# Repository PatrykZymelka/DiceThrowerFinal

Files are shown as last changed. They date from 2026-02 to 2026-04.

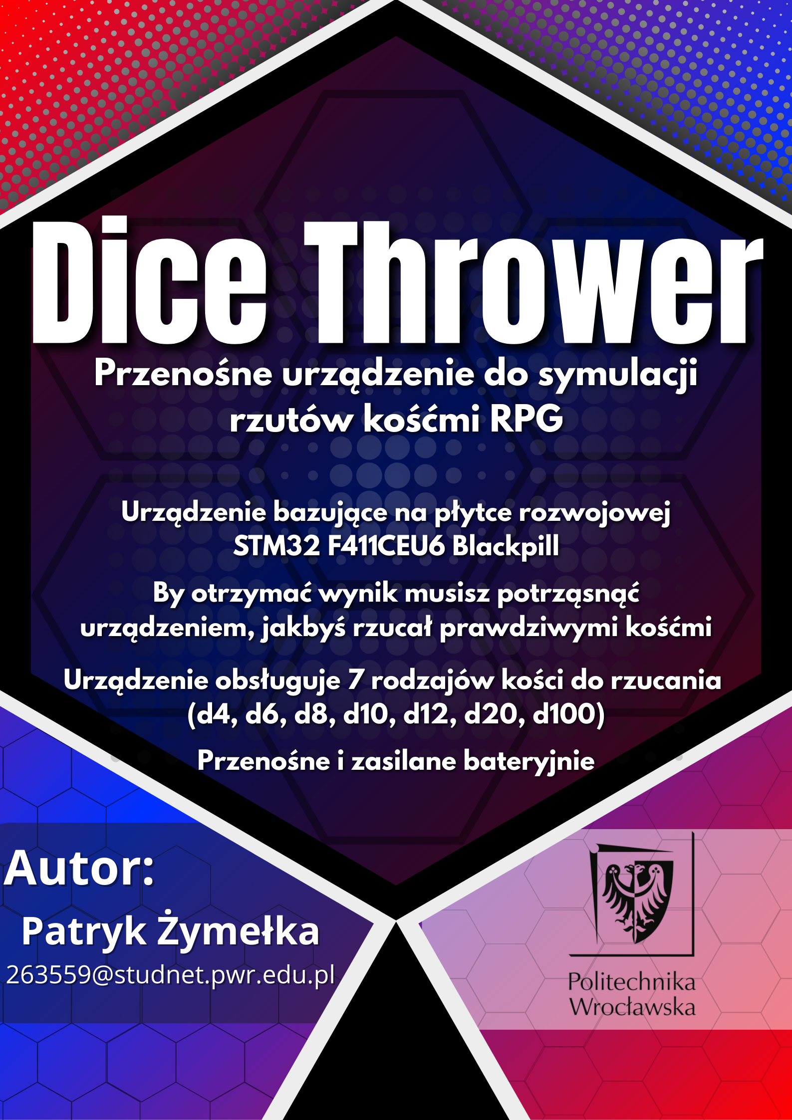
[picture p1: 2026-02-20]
Docs/Plakat.png

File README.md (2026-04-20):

Overview:

Dice thrower is a device that simulates the roll of multiple types and number of dice. With it is designed to help the user roll faster and get the result sooner, than with traditional physical dice. It is fully portable and runs on one rechargable LiON battery. located inside its case. To turn on this device you need to toggle the power switch on the right side of the device as seen below:



The device uses an OLED screen as its display, in the main menu you can see all the dice types that can be rolled and their amount, that was selected by the user.
We can roll the following 7 types of RPG dice:
- d4 (four sided die)
- d6 (six sided die)
- d8 (eight sided die)
- d10 (ten sided die)
- d12 (twelve sided die)
- d20 (twenty sided die)
- d100 (one hundred sided die)

Each type of die has its own assigned button located below the display. One additional button is the FUNC or function button which use will be explained in the results section.
To use the device firstly you need to choose the type and amount of dice you want to roll. To do so simply push the corresponding button to the type of die you want to roll. With each press you will increment the amount of dice rolled of the specific type.
You can see this on the below gif, in it we choose to roll four d20's and four d4's by simply holding down their buttons.



After selecting your dice to roll them you will need to gently shake the device, as if you were rolling real dice, when done correctly you will be notified by a quick tune comming from the speaker of the device. 
The gyroscope inside will detect sudden movement and sent the signal to the main board, to generate and display the results.
The results will be shown step by step, starting from the lowest type of die (in our case d4) and finishing on the largest type of die (in our example d20). On the result screen you will see each result individually on the top row, and the sum of all the rolls on the bottom row.
When you would want to see the next results or go back to the menu, simply bush the FUNC or function button located on the bottom right of the divice.
The following gif will display how this process works:



Hardware specification:
1) Microcontroller - Blackpill is based on the STM32F411CE microcontroller, which utilizes an ARM® 32-bit Cortex®-M4 core. This microcontroller operates at frequencies of up to 100 MHz, providing high performance for a wide range of applications. The board features 512 KB of Flash memory for firmware storage and 128 KB of SRAM for real-time data processing. The operating supply voltage ranges from 1.7V to 3.6V. Additionally, the board includes an RTC (Real-Time Clock), which is useful for applications requiring precise timekeeping. The STM32 Blackpill offers multiple communication interfaces, including USB 2.0, I2C, SPI/I2S, and USART, enabling easy integration with peripheral devices such as sensors, displays, audio devices, or communication modules. This development board can be programmed using popular development environments such as STM32CubeIDE or Arduino IDE, provided that STM32 core support and the required drivers are installed.
2) Battery - 18650 lithium-ion cell is a rechargeable battery with a typical capacity of 3000 mAh and a minimum capacity of 2900 mAh. Its nominal voltage is 3.7 V, although the actual voltage may vary depending on the state of charge. According to the specification, the maximum discharge current is 15 A, which is more than sufficient for this device.
3) Display - SH1106 1.3-inch 128x64 OLED display features a built-in SH1106 controller and supports multiple control platforms, including STM32 microcontrollers. It offers very low power consumption of 0.08 W, making it ideal for this project. The display operates in a voltage range from 3V to 5V and can function in temperatures from -30°C to 70°C. It communicates with the microcontroller via the SPI interface.
4) Accelotometer - LIS3DH 3-axis digital accelerometer, Adafruit 2809, enables acceleration measurements along the X, Y, and Z axes, allowing accurate detection of motion and device orientation. It operates at a supply voltage from 3V to 5V and communicates with the microcontroller using either I2C or SPI. The sensor provides 10-bit resolution and includes three additional analog inputs that can be read through I2C. Its measurement range is configurable and can be set to ±2 g, ±4 g, ±8 g, or ±16 g. It can also operate in Ultra Low Power Mode, where it consumes only 99 µA.
5) Step down voltage regulator -LM2596 step-down converter is a voltage reduction module operating with an input voltage range from 3.2 V to 35 V, with adjustable output voltage set via a potentiometer. Its output current ranges from 2 A to 3 A depending on thermal conditions and cooling, which is sufficient for this project. By placing the converter directly after the battery supply, stable voltage can be maintained throughout the entire operating time of the device.
6) Buzzer - MG15 buzzer is a small analog speaker with a power rating of 0.1 W and an impedance of 8 Ohms. It is used to generate an audible signal during the “dice roll” event. This is achieved by driving it with a PWM signal generated by the microcontroller.
7) Power switch - SS12T44 slide switch is a simple switch used in this project to turn the device power supply on and off.
8) Button switch - 6x6 mm THT tactile switches are standard momentary push-button switches and are fully sufficient for the requirements of this project.

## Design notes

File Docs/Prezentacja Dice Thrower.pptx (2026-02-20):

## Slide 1

- Dice Thrower
- Projekt urządzenia do symulacji rzutów kości RPG

Patryk Żymełka 263559

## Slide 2

- Koncepcja Projektu

Celem projektu jest stworzenie przenośnego urządzenia symulującego rzuty siedmioma standardowymi kośćmi wykorzystywanymi w grach fabularnych RPG (D4, D6, D8, D10, D12, D20, D100). Projekt umożliwi użytkownikowi wybór rodzaju i ilości kości a następnie potrząsając urządzeniem, wygeneruje losowy wynik, który zostanie wyświetlony na wbudowanym ekranie.

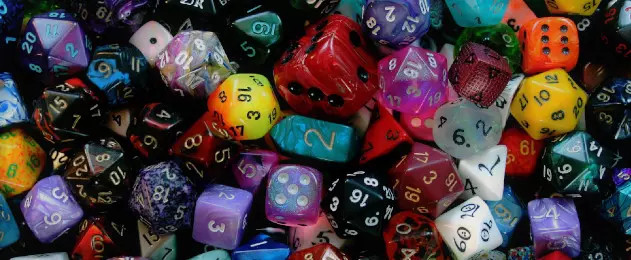
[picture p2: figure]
Zestawy kości Dungeons and Dragons – mechaniki i typowe zastosowania – Blog o RPG
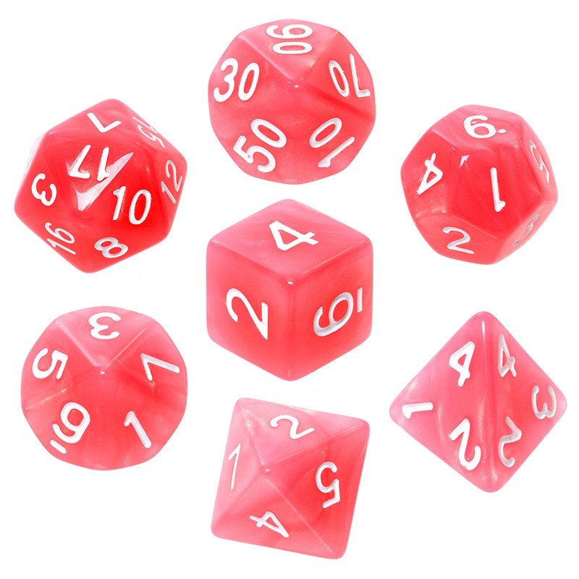
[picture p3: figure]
kości RPG Kamienie Księżycowe - Awenturyn - komplet 7 sztuk, zestaw kości - Xjoy.pl

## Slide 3

- Założenia Projektowe

- Symulator rzutów kości - Urządzenie musi mieć możliwość rzucania siedmioma rodzajami kości D4, D6, D8, D10, D12, D20, D100.
- Wyświetlanie wyników - By pokazać użytkownikowi wyniki urządzenie musi obsługiwać wyświetlacz OLED.
- Elementy Interaktywne:
A)Guziki do wybierania rodzaju i ilości kości
B)Wyświetlanie wyników poprzez potrząsanie urządzeniem
C)Element dźwiękowy przy potrząsaniu
- Przenośność - urządzenie musi być kompaktowe by można je było przenieść i używać poza domem.

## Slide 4

- ESP32 STM32F411CEU6 Blackpill Board
- Ogniwo 18650 3000mAh Li-On
- Wyświetlacz OLED SH1106 1,3" 128x64px
- 3-osiowy akcelerometr cyfrowy LIS3DH - Adafruit 2809
- Przetwornica step-down – LM2596
- Głośnik MG15 0,1W

- Główne elementy urządzenia

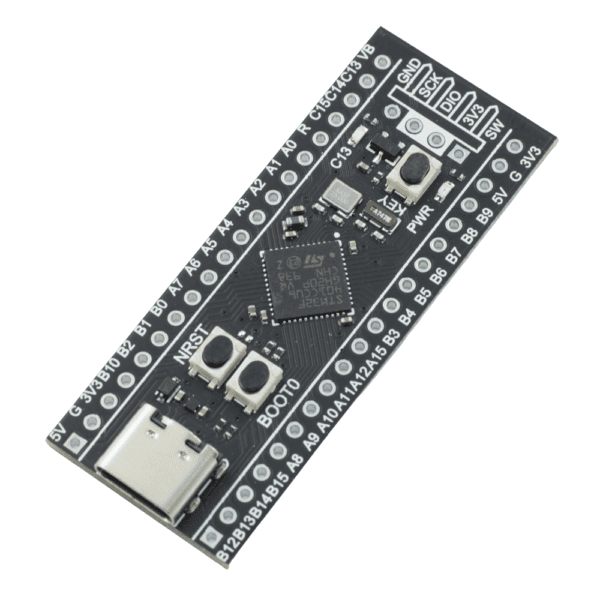
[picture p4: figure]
sklep_msalamon_STM32F4X1CXU6_EVAL_3
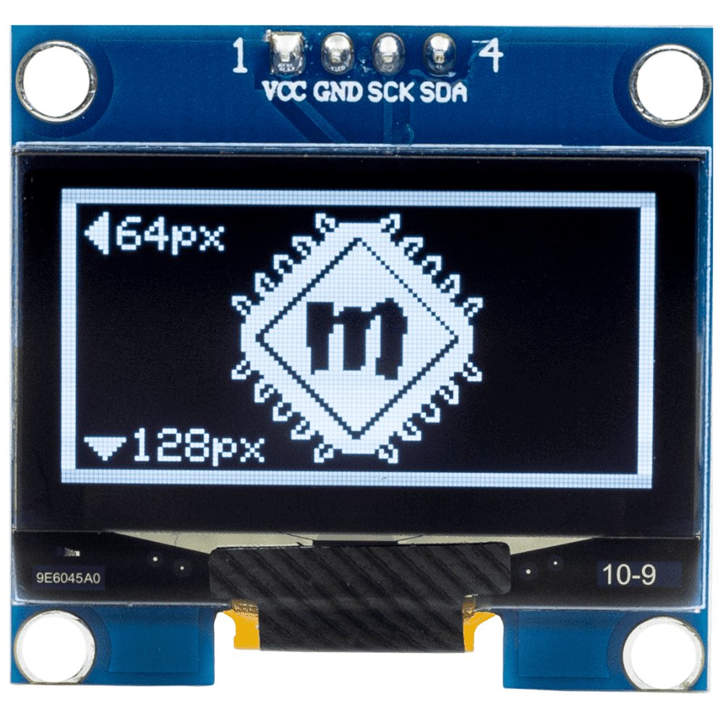
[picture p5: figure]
Wyświetlacz OLED 1,3" 128x64px I2C biały - Sklep msalamon
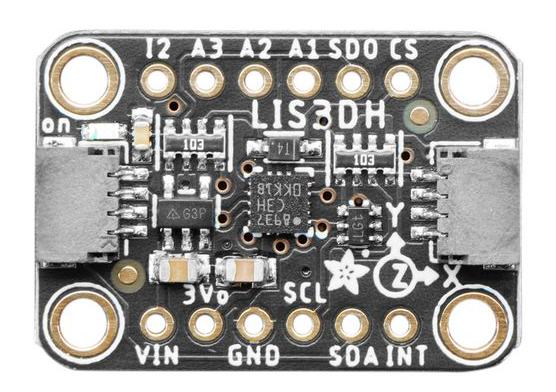
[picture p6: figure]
2809 | Adafruit Akcelerometr trzyosiowy LIS3DH, 5V | Distrelec Polska

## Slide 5

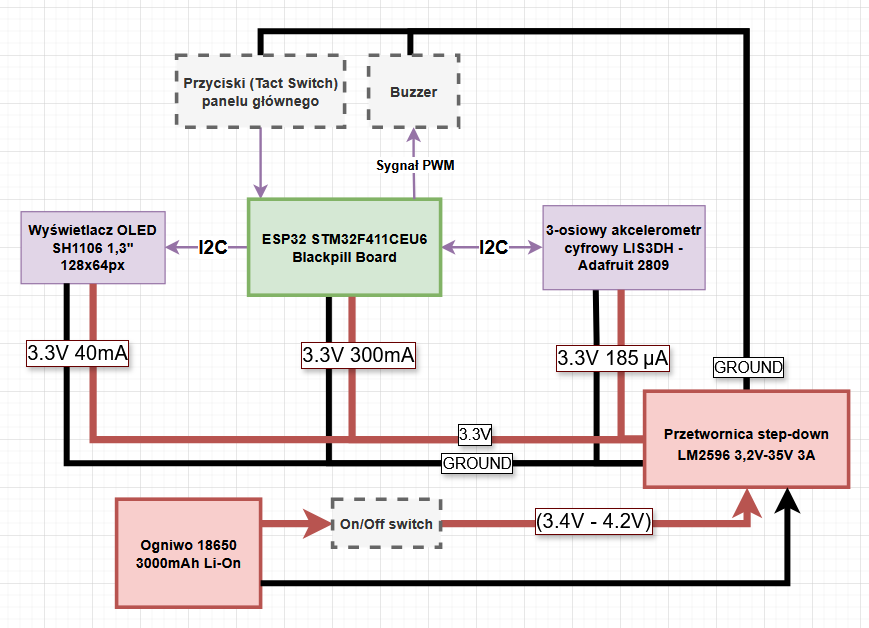
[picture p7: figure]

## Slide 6

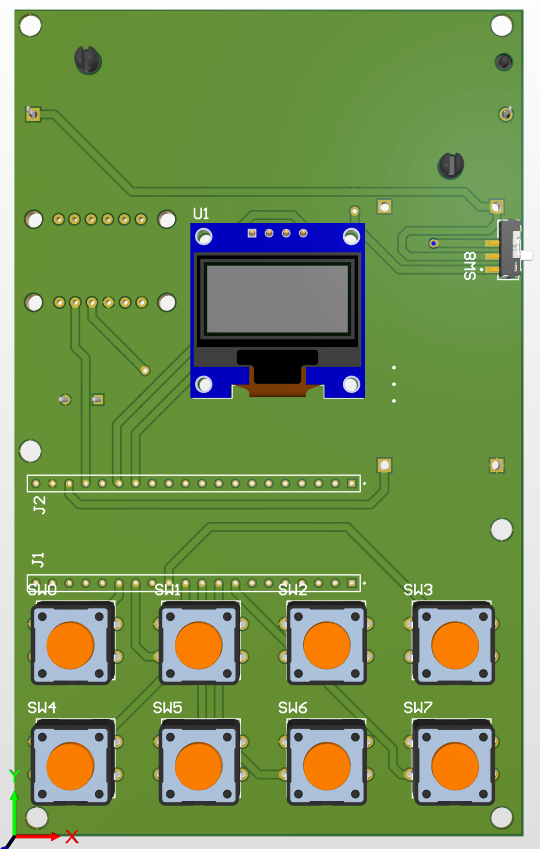
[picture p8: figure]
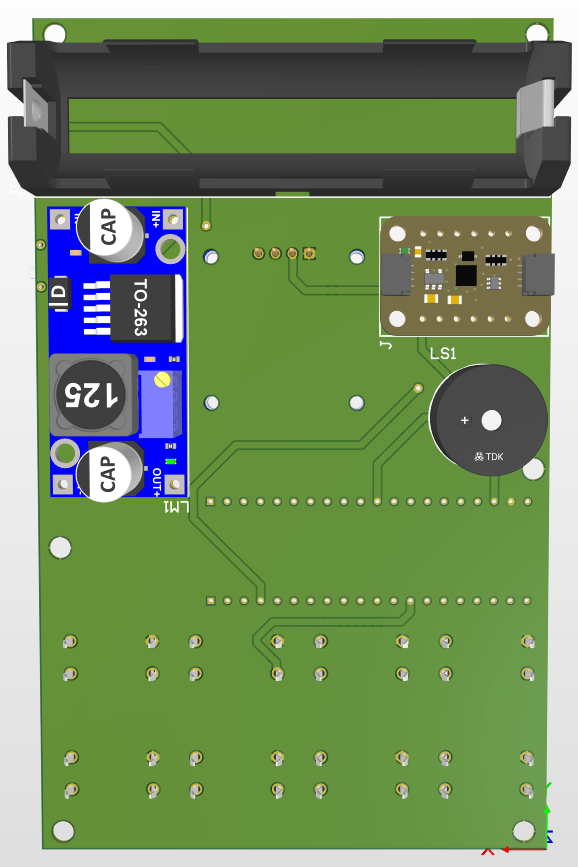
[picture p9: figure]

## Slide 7

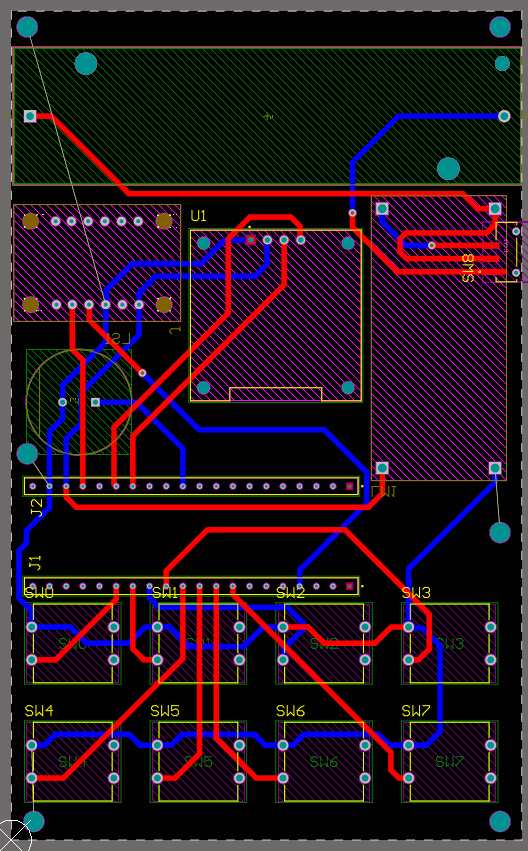
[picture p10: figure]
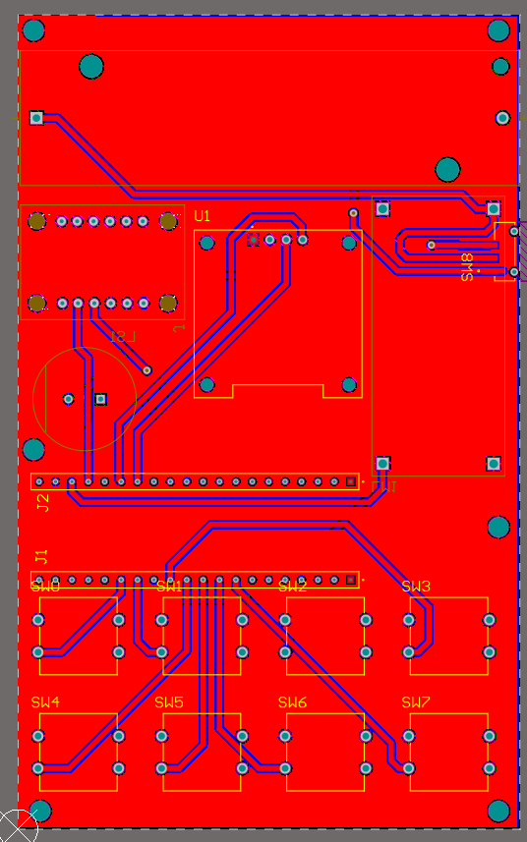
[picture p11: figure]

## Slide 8

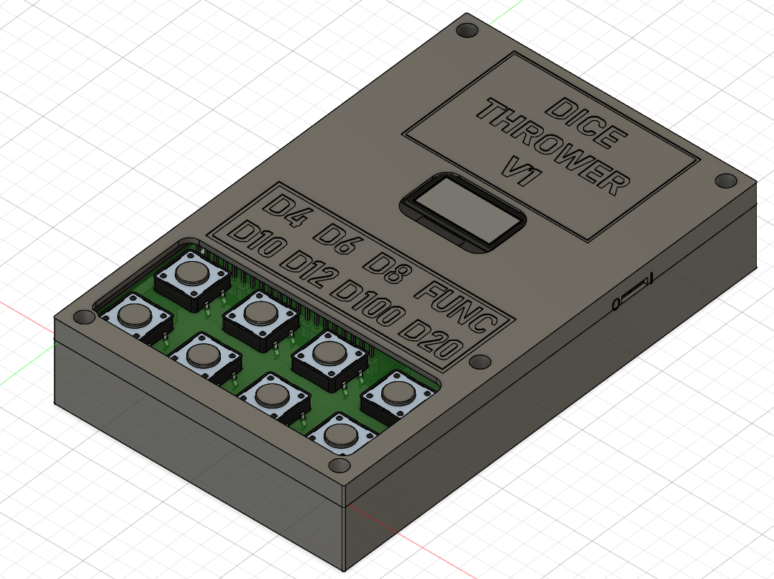
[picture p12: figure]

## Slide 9

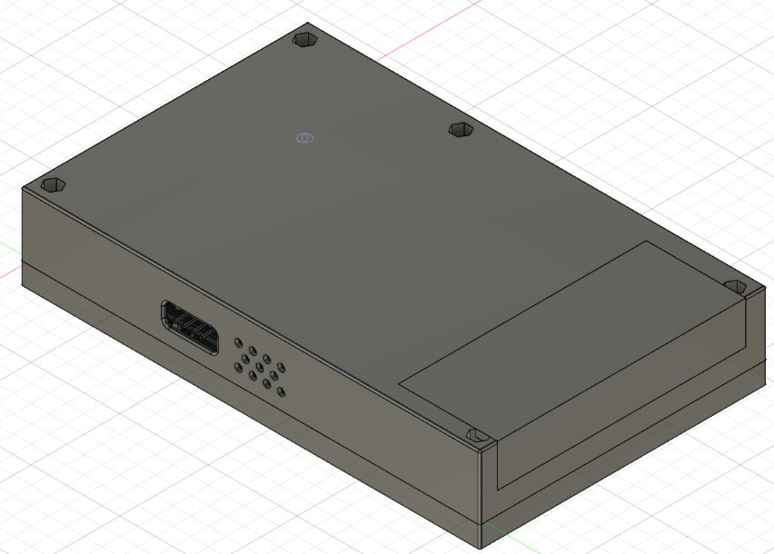
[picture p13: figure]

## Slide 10

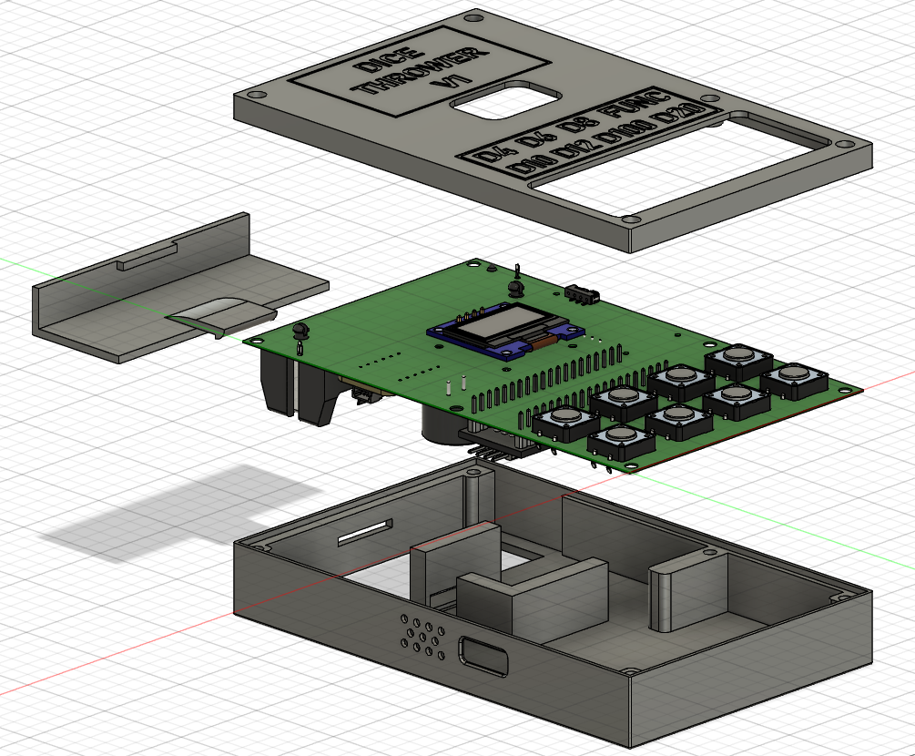
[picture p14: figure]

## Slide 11

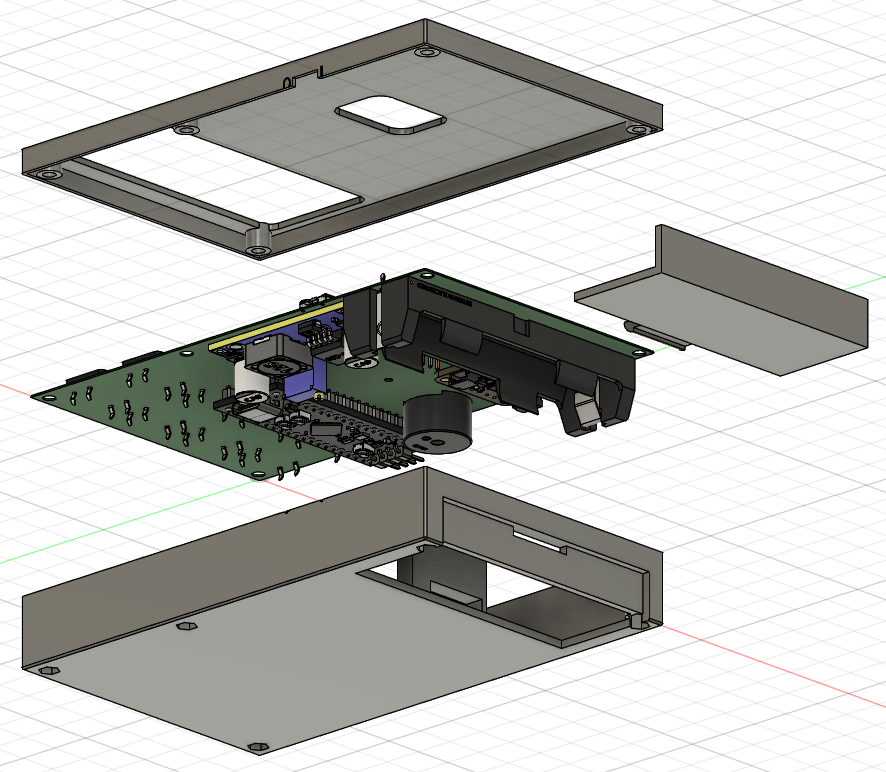
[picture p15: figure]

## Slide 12

- Diagram Logiki

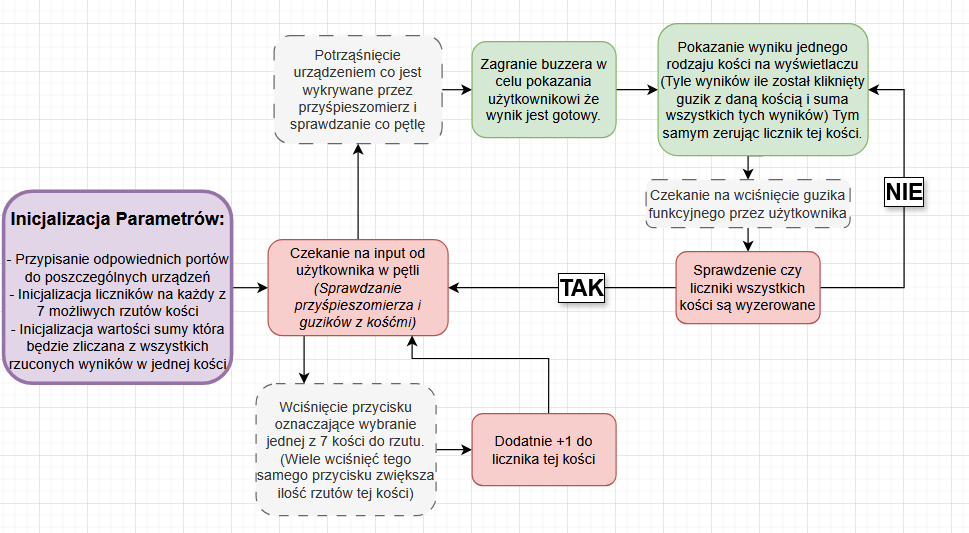
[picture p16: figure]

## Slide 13

- Zestawienie Kosztów

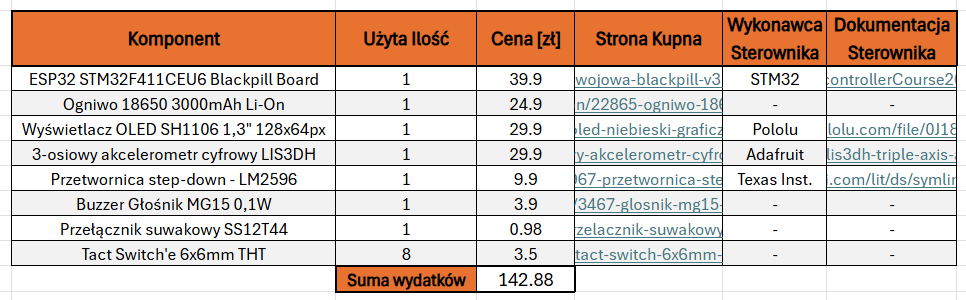
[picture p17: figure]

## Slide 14

- Dziękuję za uwagę

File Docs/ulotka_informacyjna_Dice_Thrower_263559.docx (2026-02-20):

Dice Thrower

Patryk Żymełka, Elektryczne systemy mechatroniki, II stopień, I semestr. W12N

Założenia projektowe: Celem projektu jest stworzenie przenośnego urządzenia symulującego rzuty siedmioma standardowymi kośćmi wykorzystywanymi w grach fabularnych RPG (D4, D6, D8, D10, D12, D20, D100). Projekt umożliwi użytkownikowi wybór rodzaju i ilości kości a następnie potrząsając urządzeniem, wygeneruje losowy wynik, który zostanie wyświetlony na wbudowanym ekranie. Dodatkowym elementem urządzenia będzie efekt dźwiękowy wydawany przy akcie potrząśnięcia urządzeniem.


Schemat blokowy | Parametry techniczne urządzenia: 1. ESP32 STM32F411CEU6 Blackpill - Płytka rozwojowa STM32 Blackpill oparta jest na mikrokontrolerze STM32F411CE, który wykorzystuje rdzeń ARM® 32-bit Cortex®-M4. 2. Wyświetlacz OLED SH1106 1,3" 128x64px - Wyświetlacz ten posiada wbudowany sterownik SSH1106. 3. 3-osiowy akcelerometr cyfrowy LIS3DH - Adafruit 2809 – Akcelerometr ten umożliwia pomiar przyspieszenia w trzech osiach w wybieralnym zakresie pomiarowym ±2 g, ±4 g, ±8 g lub ±16g. 4. Przetwornica step-down - LM2596 - Działa w zakresie od 3,2 V do 35 V napięcia wyjściowego oraz prądu wyjściowego do 3A.

Opis działania urządzenia: Użytkownik wybiera ilość i rodzaj kości które chce rzucić, wykonuje to poprzez klikanie odpowiednich guzików na urządzeniu. Po wybraniu tych parametrów powinien on potrząsnąć urządzeniem, co zostanie zarejestrowane przez przyśpieszomierz. W skutku czego urządzenie wyświetli wyniki poszczególnych rzutów na wyświetlaczu wraz z zagraniem muzyki z głośnika urządzenia.

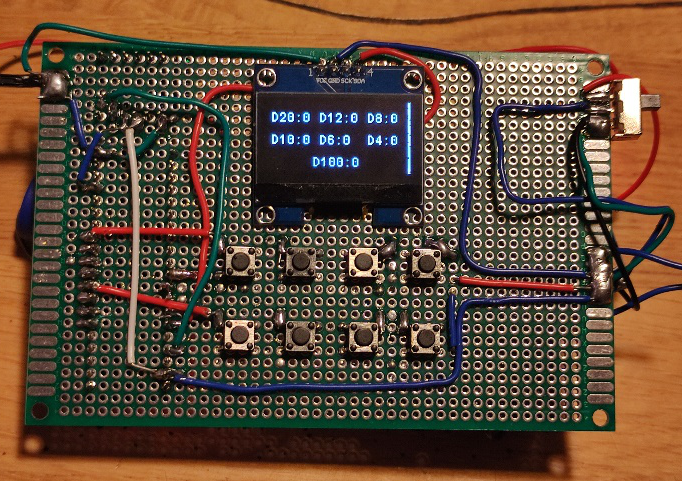
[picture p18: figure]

Wizualizacja Przyszłej wersji urządzenia | Zdjęcie gotowego urządzenia

Ewentualne dodatkowe informacje/ efekty pracy: Udało się stworzyć w pełni funkcjonalne fizyczne urządzenie widoczne na powyższym prawym zdjęciu.

Projekt zrealizowano w ramach kursu Systemy elektroniczne w mechatronice

Realizacja niniejszego projektu sfinansowana została ze środków W12/ K72/ autorów

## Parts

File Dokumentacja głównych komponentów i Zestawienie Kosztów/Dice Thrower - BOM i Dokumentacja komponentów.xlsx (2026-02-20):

Komponent | Użyta Ilość | Cena [zł] | Strona Kupna | Wykonawca Sterownika | Dokumentacja Sterownika
ESP32 STM32F411CEU6 Blackpill Board | 1 | 39.9 | https://botland.com.pl/stm32-discovery/19769-stm32f411ceu6-plytka-rozwojowa-blackpill-v31-z-mikrokontrolerem-stm32f411ceu6-weact-studio-5904422347536.html | STM32 | https://docs.scintilla.utwente.nl/cursus/MicrocontrollerCourse2015/STM32F411%20Reference%20Manual.pdf
Ogniwo 18650 3000mAh Li-On | 1 | 24.9 | https://botland.com.pl/akumulatory-li-ion/22865-ogniwo-18650-inr18650-f1hr-5c66c-3000mah.html | - | -
Wyświetlacz OLED SH1106 1,3" 128x64px | 1 | 29.9 | https://botland.com.pl/wyswietlacze-oled/8246-wyswietlacz-oled-niebieski-graficzny-13-128x64px-i2c-v2-niebieskie-znaki-5904422311339.html | Pololu | https://www.pololu.com/file/0J1813/SH1106.pdf
3-osiowy akcelerometr cyfrowy LIS3DH | 1 | 29.9 | https://botland.com.pl/akcelerometry/5295-lis3dh-3-osiowy-akcelerometr-cyfrowy-i2cspi-stemma-qt-adafruit-2809-5904422354312.html | Adafruit | https://learn.adafruit.com/adafruit-lis3dh-triple-axis-accelerometer-breakout/downloads
Przetwornica step-down - LM2596 | 1 | 9.9 | https://botland.com.pl/przetwornice-step-down/2967-przetwornica-step-down-lm2596-32v-35v-3a-5903351241397.html | Texas Inst. | https://www.ti.com/lit/ds/symlink/lm2596.pdf
Buzzer Głośnik MG15 0,1W | 1 | 3.9 | https://botland.com.pl/glosniki-analogowe/3467-glosnik-mg15-01w-8ohm-15x4mm-5903351245845.html | - | -
Przełącznik suwakowy SS12T44 | 1 | 0.98 | https://botland.com.pl/przelaczniki-spdt/8051-przelacznik-suwakowy-ss12t44-2-pozycyjny-5szt-5904422304218.html | - | -
Tact Switch'e 6x6mm THT | 8 | 3.5 | https://botland.com.pl/tact-switch/3495-tact-switch-6x6mm-5mm-tht-2pin-5szt-5904422307639.html | - | -
 | Suma wydatków | 142.88

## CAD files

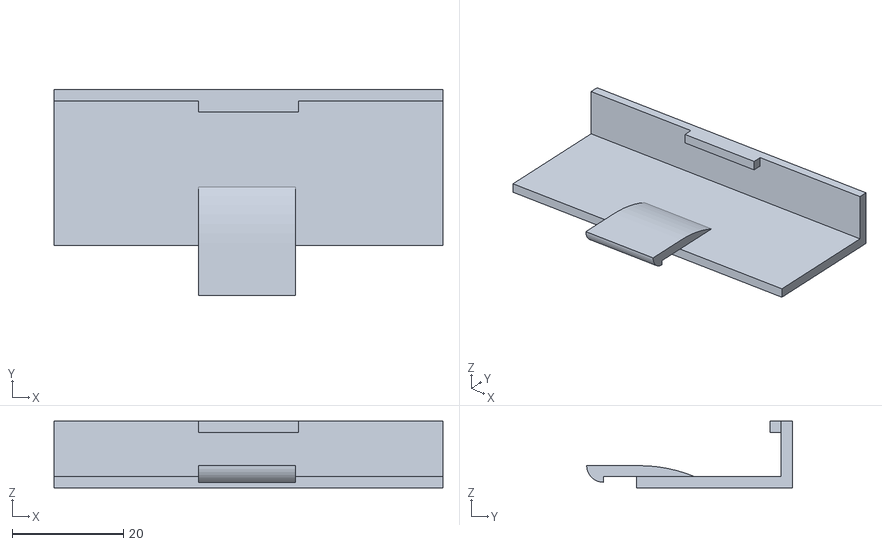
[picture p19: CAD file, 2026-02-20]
Dice Thrower Case - Fusion 360 files/Dice Thrower v13 - Battery Cover.stl
70.0 x 37.0 x 12.0

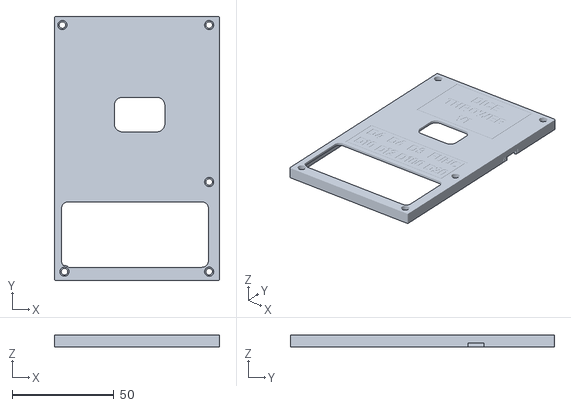
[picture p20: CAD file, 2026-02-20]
Dice Thrower Case - Fusion 360 files/Dice Thrower v13 - Top Part.stl
81.0 x 129.5 x 6.00

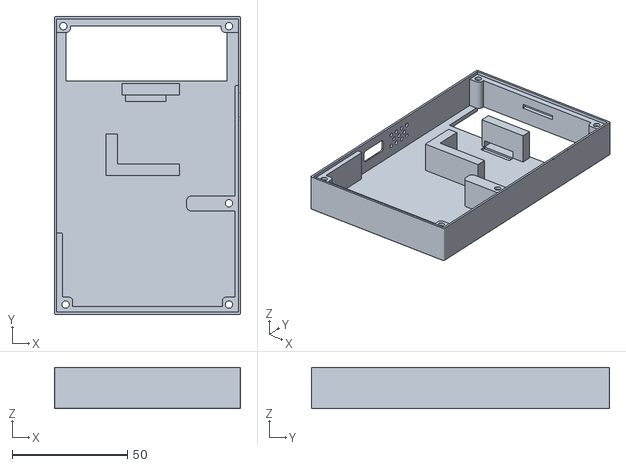
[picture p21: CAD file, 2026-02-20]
Dice Thrower Case - Fusion 360 files/Dice Thrower v13 - Bottom Part.stl
81.0 x 129.5 x 18.0

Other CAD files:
Dice Thrower Case - Fusion 360 files/Dice Thrower v12.f3d

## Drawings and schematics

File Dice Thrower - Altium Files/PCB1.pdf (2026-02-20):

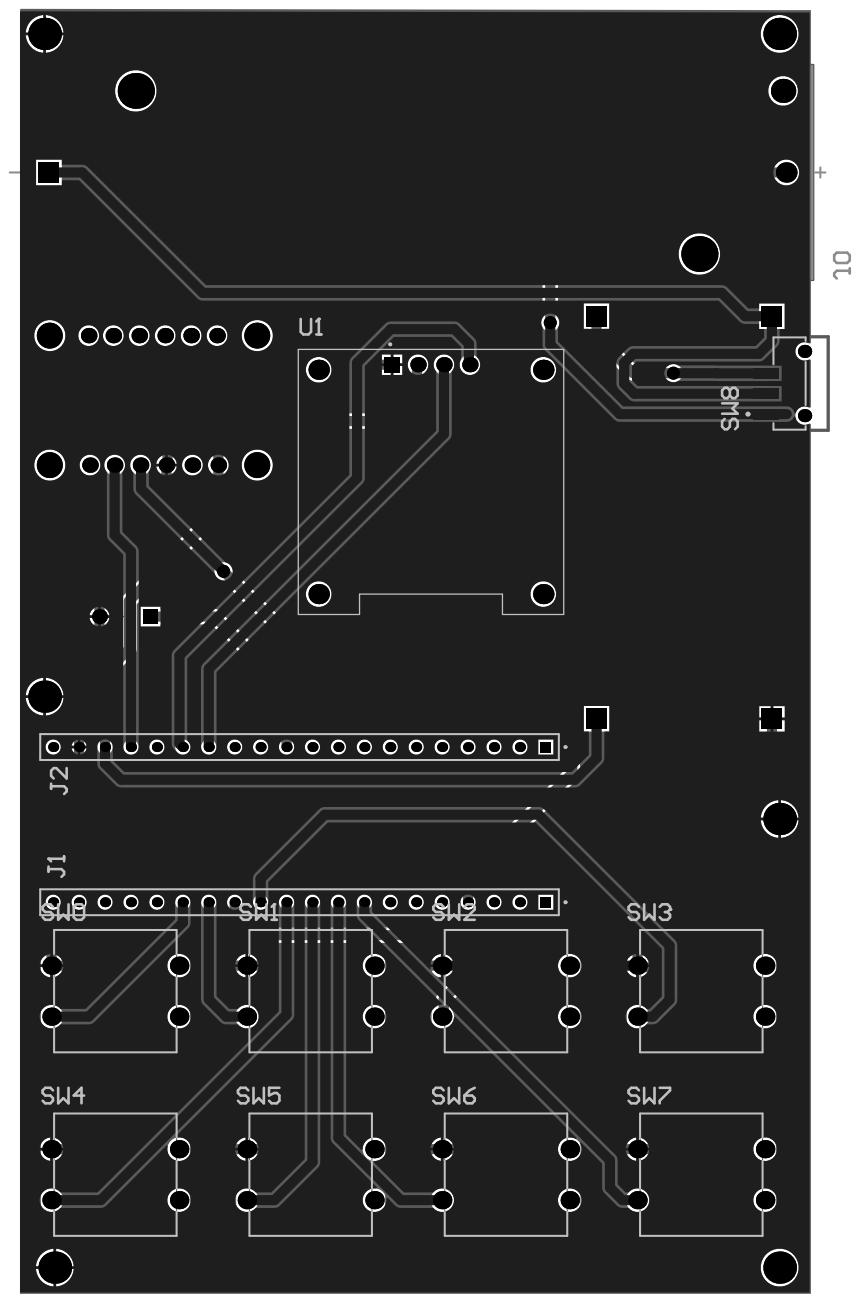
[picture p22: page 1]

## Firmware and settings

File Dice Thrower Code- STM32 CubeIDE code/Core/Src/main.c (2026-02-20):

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
/* Includes ------------------------------------------------------------------*/
#include "main.h"

/* USER CODE BEGIN Includes */
#include "fonts.h"
#include "ssd1306.h"
#include "lis3dh_driver.h"
#include <math.h>
#include <stdio.h>
/* USER CODE END Includes */

I2C_HandleTypeDef hi2c1;
I2C_HandleTypeDef hi2c2;

TIM_HandleTypeDef htim2;

UART_HandleTypeDef huart1;

void SystemClock_Config(void);
static void MX_GPIO_Init(void);
static void MX_I2C1_Init(void);
static void MX_I2C2_Init(void);
static void MX_TIM2_Init(void);
static void MX_USART1_UART_Init(void);
/* USER CODE BEGIN 0 */
uint32_t seed = 128758;

uint32_t RandomNumber(uint32_t min, uint32_t max) {
    seed = (1664525 * seed + 1013904223) % 0xFFFFFFFF;
    return (seed % (max - min + 1)) + min;
}
//Licznik dla każdej kości ile rzutów trzeba wykonać, zwiększa się wraz z klikaniem tego guzika
uint8_t d4Number = 0;
uint8_t d6Number = 0;
uint8_t d8Number = 0;
uint8_t d10Number = 0;
uint8_t d12Number = 0;
uint8_t d20Number = 0;
uint8_t d100Number = 0;

//Licznik dla każdej z kości jaka jest suma rzutów w danej "epoce"
uint32_t d4Counter = 0;
uint32_t d6Counter = 0;
uint32_t d8Counter = 0;
uint32_t d10Counter = 0;
uint32_t d12Counter = 0;
uint32_t d20Counter = 0;
uint32_t d100Counter = 0;

//Czyszczenie bufferu
void ClearBuffer(char* buffer, uint16_t size) {
    for (uint16_t i = 0; i < size; i++) {
        buffer[i] = '\0';
    }
}


void HomeScreen(){
	char buffer[40];
	SSD1306_Clear();
	//Po kolei pójście w daną część wyświetlacza i pisanie tam danej kości i ile rzutów wybrał użytkownik
	SSD1306_GotoXY(5, 10);
	SSD1306_Puts("D20:", &Font_7x10, 1);
	sprintf(buffer, "%u",d20Number);
	SSD1306_Puts(buffer, &Font_7x10, 1);

	SSD1306_GotoXY(48, 10);
	SSD1306_Puts("D12:", &Font_7x10, 1);
	sprintf(buffer, "%u",d12Number);
	SSD1306_Puts(buffer, &Font_7x10, 1);

	SSD1306_GotoXY(91, 10);
	SSD1306_Puts("D8:", &Font_7x10, 1);
	sprintf(buffer, "%u",d8Number);
	SSD1306_Puts(buffer, &Font_7x10, 1);

	SSD1306_GotoXY(5, 30);
	SSD1306_Puts("D10:", &Font_7x10, 1);
	sprintf(buffer, "%u",d10Number);
	SSD1306_Puts(buffer, &Font_7x10, 1);

	SSD1306_GotoXY(48, 30);
	SSD1306_Puts("D6:", &Font_7x10, 1);
	sprintf(buffer, "%u",d6Number);
	SSD1306_Puts(buffer, &Font_7x10, 1);

	SSD1306_GotoXY(91, 30);
	SSD1306_Puts("D4:", &Font_7x10, 1);
	sprintf(buffer, "%u",d4Number);
	SSD1306_Puts(buffer, &Font_7x10, 1);

	SSD1306_GotoXY(42, 50);
	SSD1306_Puts("D100:", &Font_7x10, 1);
	sprintf(buffer, "%u",d100Number);
	SSD1306_Puts(buffer, &Font_7x10, 1);
	//Po napisaniu wszystkich elementów na ekranie trzeba pamiętać by cały ekran zupdateować
	SSD1306_UpdateScreen();
	//Delay dla pełnego przepływu danych
	HAL_Delay(200);
}


void Display(uint16_t end, uint8_t i){
	//Czyści co jest teraz
	SSD1306_Clear();
	//Pozycjunuje kursor w danym miejscu ekranu
	SSD1306_GotoXY(5, 0);

	//Przemiana z int na char
	char buffer[40];
	sprintf(buffer, "Dice D%u:", end);

	//Pisze wynik na ekranie
	SSD1306_Puts(buffer, &Font_7x10, 1);

	SSD1306_GotoXY(5, 20);

	for(int j = 0; j < i; j++){
	//Losuje numer z zakresu kości i go wstawia na ekran
		int n = RandomNumber(1, end);
		sprintf(buffer, "%lu ", n);
		SSD1306_Puts(buffer, &Font_7x10, 1);
		//Switch case by dodać dany losowy rzut do countera czyli sumy, każda kość ma osobną sumę
		switch(end){
			case 4:
				d4Counter = d4Counter + n;
				break;
			case 6:
				d6Counter = d6Counter + n;
				break;
			case 8:
				d8Counter = d8Counter + n;
				break;
			case 10:
				d10Counter = d10Counter + n;
				break;
			case 12:
				d12Counter = d12Counter + n;
				break;
			case 20:
				d20Counter = d20Counter + n;
				break;
			case 100:
				d100Counter = d100Counter + n;
				break;

			}
	}
	SSD1306_GotoXY(5, 40);
	//Po pokazaniu wszystkich wyników i zliczeniu sum, pokazujemy sumę danej kości
	switch(end){
		case 4:
			sprintf(buffer, "Sum: %lu", d4Counter);
			SSD1306_Puts(buffer, &Font_7x10, 1);
			break;
		case 6:
			sprintf(buffer, "Sum: %lu", d6Counter);
			SSD1306_Puts(buffer, &Font_7x10, 1);
			break;
		case 8:
			sprintf(buffer, "Sum: %lu", d8Counter);
			SSD1306_Puts(buffer, &Font_7x10, 1);
			break;
		case 10:
			sprintf(buffer, "Sum: %lu", d10Counter);
			SSD1306_Puts(buffer, &Font_7x10, 1);
			break;
		case 12:
			sprintf(buffer, "Sum: %lu", d12Counter);
			SSD1306_Puts(buffer, &Font_7x10, 1);
			break;
		case 20:
			sprintf(buffer, "Sum: %lu", d20Counter);
			SSD1306_Puts(buffer, &Font_7x10, 1);
			break;
		case 100:
			sprintf(buffer, "Sum: %lu", d100Counter);
			SSD1306_Puts(buffer, &Font_7x10, 1);
			break;
		}
	//Oczywiście na końcu musimy wyzerować sumę dla wszystkich kości by kolejna "epoka" zaczynała od zera
	switch(end){
		case 4:
			d4Counter = 0;
			break;
		case 6:
			d6Counter = 0;
			break;
		case 8:
			d8Counter = 0;
			break;
		case 10:
			d10Counter = 0;
			break;
		case 12:
			d12Counter = 0;
			break;
		case 20:
			d20Counter = 0;
			break;
		case 100:
			d100Counter = 0;
			break;
		}
	//Pokazanie napianych rzeczy na ekranie
	SSD1306_UpdateScreen();

	HAL_Delay(1000);

}


void Buzz(){
	//Wysyłamy sygnał PWM na port gdzie jest połączony nasz głośnik
	HAL_TIM_PWM_Start(&htim2, TIM_CHANNEL_2);
	int x;
	//Wysyłamy po kolei od niższych do wyższych częstotliwości i odwrotnie by dać ciekawy dźwięk
	for(x = 30; x < 40; x++) {
	    __HAL_TIM_SET_AUTORELOAD(&htim2, x * 2);
	    __HAL_TIM_SET_COMPARE(&htim2, TIM_CHANNEL_2, x);
	    HAL_Delay(50);
	  }
	for(x = 40; x < 30; x++) {
		__HAL_TIM_SET_AUTORELOAD(&htim2, x * 2);
		__HAL_TIM_SET_COMPARE(&htim2, TIM_CHANNEL_2, x);
		HAL_Delay(50);
	  }
	HAL_TIM_PWM_Stop(&htim2, TIM_CHANNEL_2);
}

void DisplayResult(){
	//Funkcja która pokazuje po kolei wyniki od najniższego do najwyższego rodzaju kości
	if(d4Number != 0){
		Display(4, d4Number);
		d4Number = 0;
	}
	else if(d6Number != 0){
		Display(6, d6Number);
		d6Number = 0;
	}
	else if(d8Number != 0){
		Display(8, d8Number);
		d8Number = 0;
	}
	else if(d10Number != 0){
		Display(10, d10Number);
		d10Number = 0;
	}
	else if(d12Number != 0){
		Display(12, d12Number);
		d12Number = 0;
	}
	else if(d20Number != 0){
		Display(20, d20Number);
		d20Number = 0;
	}
	else if(d100Number != 0){
		Display(100, d100Number);
		d100Number = 0;
	}

}
void RollDice(){
	//Głośnik gra muzykę by pokazać że wynik jest gotowy
	Buzz();
	//Pokazujemy pierwszą kość
	DisplayResult();
	while(d4Number != 0 || d6Number != 0 || d8Number != 0 || d10Number != 0 || d12Number != 0 || d20Number != 0 || d100Number != 0){

		if (HAL_GPIO_ReadPin(A0_GPIO_Port, A0_Pin) == 0) {
				DisplayResult();
		}
	}
	//Czekamy na ostatnie kliknięcie guzika funkcyjnego by przejść do menu głównego
	while(HAL_GPIO_ReadPin(A0_GPIO_Port, A0_Pin) != 0){}
		HomeScreen();


}

/* USER CODE END 0 */

/**
  * @brief  The application entry point.
  * @retval int
  */
int main(void)
{

  /* MCU Configuration--------------------------------------------------------*/

  /* Reset of all peripherals, Initializes the Flash interface and the Systick. */
  HAL_Init();

  /* Configure the system clock */
  SystemClock_Config();

  /* Initialize all configured peripherals */
  MX_GPIO_Init();
  MX_I2C1_Init();
  MX_I2C2_Init();
  MX_TIM2_Init();
  MX_USART1_UART_Init();
  /* USER CODE BEGIN 2 */
  HAL_TIM_PWM_Start(&htim2, TIM_CHANNEL_2);
  SSD1306_Init();

  /* USER CODE END 2 */

  /* Infinite loop */
  /* USER CODE BEGIN WHILE */
  //Na początek pokazujemy home screen by zawsze był on pierwszą rzeczą jaką będzie widział użytkownik
  HomeScreen();
  int x = 0;
  //Inicjalizujemy przyśpieszomierz
  LIS3DH_Init(&hi2c2);
  while (1)
  {
    /* USER CODE END WHILE */

    /* USER CODE BEGIN 3 */

	  //Czytamy i sumujemy dane z przyśpieszomierza zamieniając je na ogólne przyśpieszenie urządzenia
	  int16_t x_raw, y_raw, z_raw;
	  LIS3DH_ReadRawAcc(&hi2c2, &x_raw, &y_raw, &z_raw);

	  float ax = x_raw * 0.001f * 9.81f;
	  float ay = y_raw * 0.001f * 9.81f;
	  float az = z_raw * 0.001f * 9.81f;

	  float magnitude = sqrt(ax * ax + ay * ay + az * az);
	  float net_accel = fabs(magnitude - 9.81f);
	  //Jeżeli przyśpieszomierz odzyczyta odpowiednią szybkość rzucamy kośćmi które przygotowaliśmy wcześniej
	  if (net_accel > 10.0f) {
		  RollDice();
	  }


	  //Sprawdzamy czy jakikolwiek z guzików został kliknięty i update'ujemy home screen by dać instant feedback użytkownikowi
	if (HAL_GPIO_ReadPin(A1_GPIO_Port, A1_Pin) == 0) {
			d4Number++;
			HomeScreen();
	}
	if (HAL_GPIO_ReadPin(A2_GPIO_Port, A2_Pin) == 0) {
			d6Number++;
			HomeScreen();
	}
	if (HAL_GPIO_ReadPin(A3_GPIO_Port, A3_Pin) == 0) {
			d8Number++;
			HomeScreen();
	}
	if (HAL_GPIO_ReadPin(A4_GPIO_Port, A4_Pin) == 0) {
			d10Number++;
			HomeScreen();
	}
	if (HAL_GPIO_ReadPin(A5_GPIO_Port, A5_Pin) == 0) {
			d12Number++;
			HomeScreen();
	}
	if (HAL_GPIO_ReadPin(A6_GPIO_Port, A6_Pin) == 0) {
			d20Number++;
			HomeScreen();
	}
	if (HAL_GPIO_ReadPin(A7_GPIO_Port, A7_Pin) == 0) {
			d100Number++;
			HomeScreen();
	}
	HAL_Delay(200);
  }

  /* USER CODE END 3 */
}

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


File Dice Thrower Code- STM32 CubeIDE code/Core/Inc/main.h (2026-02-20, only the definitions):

#define A0_Pin GPIO_PIN_0
#define A0_GPIO_Port GPIOA
#define A1_Pin GPIO_PIN_1
#define A1_GPIO_Port GPIOA
#define A2_Pin GPIO_PIN_2
#define A2_GPIO_Port GPIOA
#define A3_Pin GPIO_PIN_3
#define A3_GPIO_Port GPIOA
#define A4_Pin GPIO_PIN_4
#define A4_GPIO_Port GPIOA
#define A5_Pin GPIO_PIN_5
#define A5_GPIO_Port GPIOA
#define A6_Pin GPIO_PIN_6
#define A6_GPIO_Port GPIOA
#define A7_Pin GPIO_PIN_7
#define A7_GPIO_Port GPIOA
#define IA9_Pin GPIO_PIN_9
#define IA9_GPIO_Port GPIOA

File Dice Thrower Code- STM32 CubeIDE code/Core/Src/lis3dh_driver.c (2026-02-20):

#include "lis3dh_driver.h"
#include "stm32f4xx_hal.h"

uint8_t LIS3DH_Init(I2C_HandleTypeDef *hi2c) {
    uint8_t ctrl1 = 0x57;  // 100Hz, all axes enabled
    uint8_t ctrl4 = 0x00;  // ±2g, High-resolution mode

    HAL_I2C_Mem_Write(hi2c, LIS3DH_ADDR, LIS3DH_REG_CTRL1, 1, &ctrl1, 1, HAL_MAX_DELAY);
    HAL_I2C_Mem_Write(hi2c, LIS3DH_ADDR, LIS3DH_REG_CTRL4, 1, &ctrl4, 1, HAL_MAX_DELAY);

    uint8_t id = 0;
    HAL_I2C_Mem_Read(hi2c, LIS3DH_ADDR, LIS3DH_REG_WHO_AM_I, 1, &id, 1, HAL_MAX_DELAY);
    return (id == LIS3DH_WHO_AM_I_ID);
}

void LIS3DH_ReadRawAcc(I2C_HandleTypeDef *hi2c, int16_t *x, int16_t *y, int16_t *z) {
    uint8_t data[6];
    HAL_I2C_Mem_Read(hi2c, LIS3DH_ADDR, LIS3DH_REG_OUT_X_L | 0x80, 1, data, 6, HAL_MAX_DELAY);

    *x = ((int16_t)(data[1] << 8 | data[0])) >> 4;
    *y = ((int16_t)(data[3] << 8 | data[2])) >> 4;
    *z = ((int16_t)(data[5] << 8 | data[4])) >> 4;
}

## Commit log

2026-02-20 Git Project Upload
    [D24V5xA.PcbLib, D24V5xA.SchLib, Dice Thrower - BOM i Dokumentacja komponentów.xlsx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]
2026-04-20 Enhance README with device overview and specs
    Added detailed overview and hardware specifications for the Dice Thrower device, including descriptions of components and their functionalities.

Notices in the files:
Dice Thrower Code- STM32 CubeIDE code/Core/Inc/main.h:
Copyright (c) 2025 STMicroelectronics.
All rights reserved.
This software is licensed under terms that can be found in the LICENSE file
